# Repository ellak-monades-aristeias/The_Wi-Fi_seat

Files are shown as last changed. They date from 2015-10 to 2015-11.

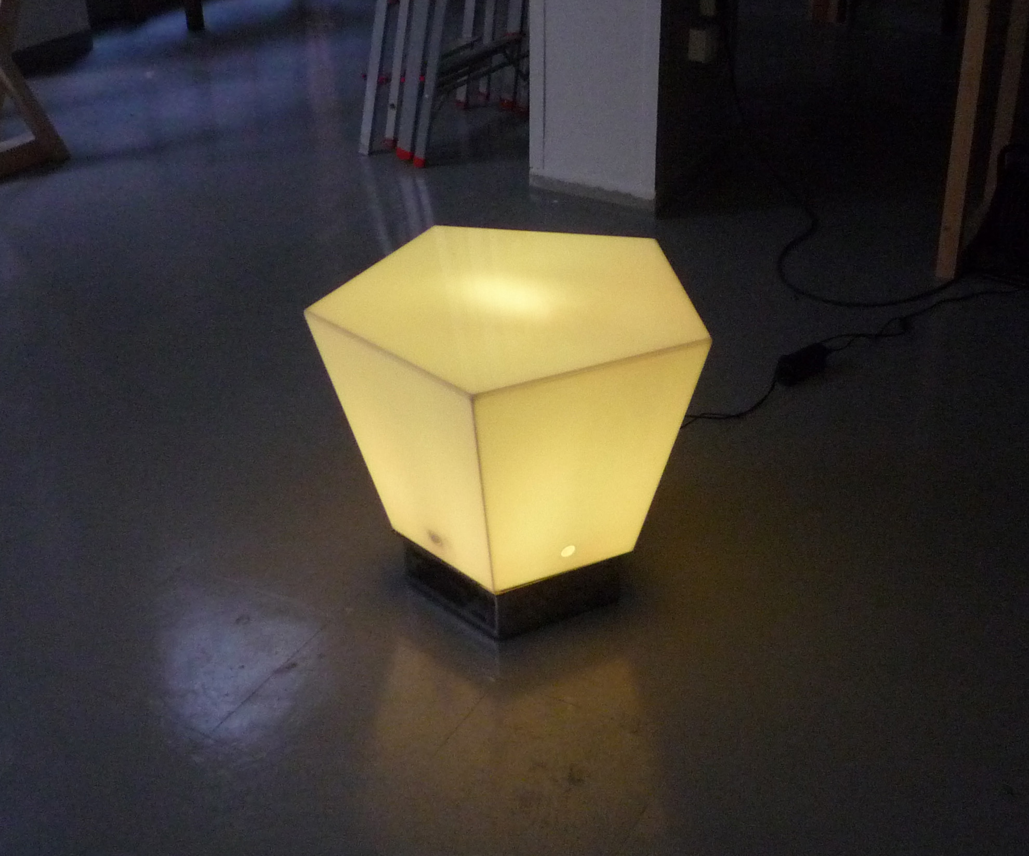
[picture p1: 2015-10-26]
images/signal_5.jpg

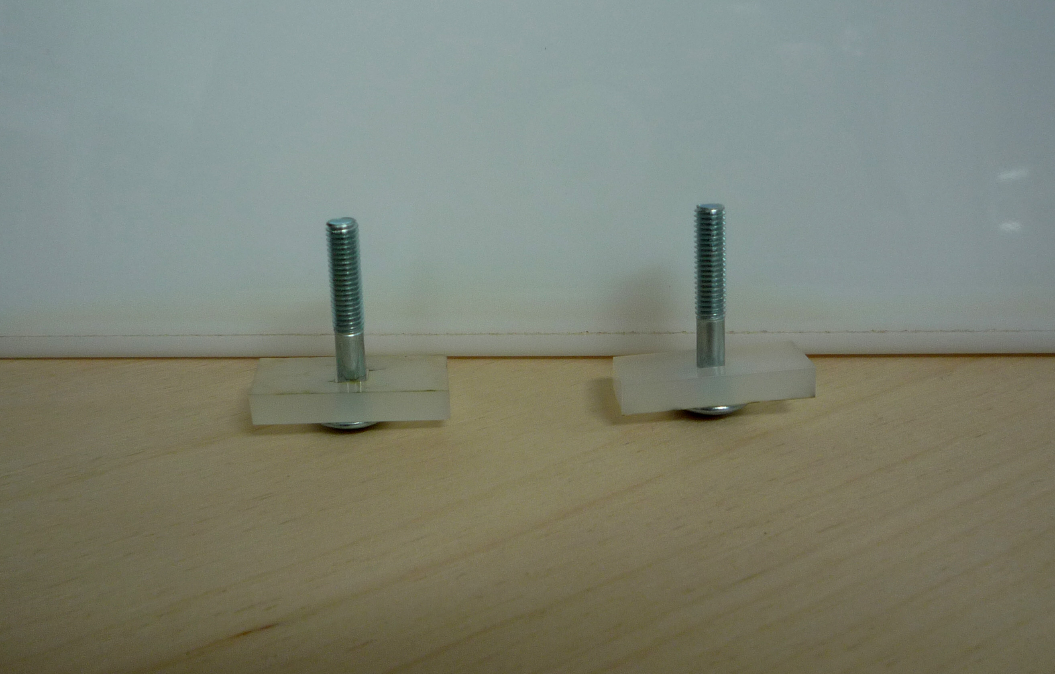
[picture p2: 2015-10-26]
images/screw_fixing_2.JPG

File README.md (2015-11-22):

# The_Wi-Fi_seat
## Περιγραφή της Πρότασης

Το Wi-Fi seat είναι κάθισμα εξωτερικού χώρου με ενσωματωμένο router που δίνει ελεύθερη πρόσβαση στο διαδίκτυο. Το κάθισμα κατασκευάζεται από plexiglass και είναι φωτιζόμενο. Ο φωτισμός διαφοροποιείται ως προς το χρώμα και ως προς την ένταση. Το χρώμα διαφοροποιείται από έντονο κόκκινο εως πράσινο αποτυπώνοντας την ένταση του σήματος Wi-Fi στην περιοχή. Η ένταση του φωτισμού του καθίσματος ρυθμίζεται ανάλογα με την κίνηση. Αν περνάει κάποιος κοντά στο κάθισμα, η ένταση θα δυναμώνει, αλλιώς θα είναι χαμηλή. Επιπλέον, η ένταση ρυθμίζεται ανάλογα με τον διάχυτο φωτισμό στην περιοχή.

Σκόπός της πρότασης είναι η δημιουργία ενός πόλου έλξης που θα ενθαρρύνει τη χρήση του δημόσιου χώρου από τους πολίτες, προσθέτοντας επιπλέον ασφάλεια μετά τη δύση του ηλίου (λόγω του φωτισμού), χωρίς να κοστίζει πολύ (λόγω της ρύθμισης της έντασης του φωτισμού).

Επιπλέον, με τη χρήση πολλών τέτοιων καθισμάτων σε διαφορετικά σημεία, δημιουργείται και ένα εικαστικό έργο που αποτυπώνει την ένταση του δικτύου WI-Fi της περιοχής. Έτσι οπτικοποιείται ένα πρόσθετο επίπεδο πληροφορίας που συνδέεται με το δομημένο περιβάλλον.

## Description

This is a perspex (plexiglass) seat for outdoor use that includes a wi-fi router, thus enabling up to 8 people to use the internet. The seat may work as a stand-alone wi-fi source, or as a mesh network (in a group of seats) that expands the municipality hotspots.

The seat is internally lit by led strips. The light colour is modified (from red to green) according to the strenght of the area wi-fi signal, the ambient lighting and nearby movement.

As a result, the seat encourages people to use public space and acts as a light source, adding an extra  sense of security  at a low cost. A group of Wi-Fi seats act as an artwork, visualizing the signal strenght as an extra information layer in the urban fabric.

## Κατασκευή

Το κάθισμα έχει μορφή κωνικού πενταγώνου, με τη μικρή διάμετρο στη βάση. Aποτελείται από τρία διακριτά στοιχεία: τη βάση, το περίβλημα και τον εσωτερικό πυρήνα.

Η βάση (σήματος πενταγώνου) κατασκευάζεται από μεταλλική γωνία 10x4cm, που βιδώνεται στο έδαφος με ειδικούς πείρους, και μεταλλική λάμα που εξέχει από την γωνία κατά 2cm, έτσι ώστε να υποδεχθεί το περίβλημα. Η λάμα έχει ειδικά ανοίγματα έτσι ώστε να υποδεχθεί τον εσωτερικό πυρήνα. Η βάση είναι γαλβανισμένη με ηλεκτροστατική βαφή.

Το περίβλημα κατασκευάζεται από φύλλα plexiglass, πάχους 10mm. Ο εσωτερικός πυρήνας έχει ορθογωνικό σχήμα και κατασκευάζεται από κόντρα πλακέ θαλάσσης 4mm. Οι πλευρές του είναι δυνατόν να κατασκευάστουν σε CNC καθώς «κουμπώνουν» η μία μέσα στην άλλη. Στην εξωτερική του πλευρά του στερεώνονται ταινίες led. Στο εσωτερικό του τοποθετείται ο διακομιστής (router), η κεραία, ο σένσορας έντασης του σήματος wi-fi καθώς και η πλακέτα που θα ρυθμίζει το χρώμα και την ένταση του φωτός, τύπου Arduino.

## Σύνδεση Wi-Fi

Το Wi-Fi seat διατίθεται σε δύο εκδόσεις από άποψη συνδεσιμότητας στο διαδίκτυο (Internet). Η μια διαθέτει δρομολογητή (router) με δυνατότητα διασύνδεσης τύπου 4G LTE ή 3G και παρέχει αυτόνομη πρόσβαση. Η δεύτερη διαθέτει δρομολογητή με δυνατότητα διασύνδεσης με άλλους δρομολογητές για την δημιουργία δικτύου πλέγματος (mesh network).

Η πρώτη έκδοση με αυτόνομο internet θα χρησιμοποιεί έναν δρομολογητή (router) τύπου D-Link 4G LTE. Προτιμήθηκε αυτός ο τύπος σε σχέση με κάποια έκδοση δρομολογητή με ανοιχτό λογισμικό (όπως τα OpenWrt, DD-WRT και HyperWRT) καθώς δεν υπάρχει διαθεσιμότητα ώριμης ανοιχτής λύσης ασύρματης δικτύωσης με διασύνδεση 4G LTE. Εναλλακτικά μπορεί να χρησιμοποιηθεί δρομολογητής TP-Link TL-MR3020 με λογισμικό OpenWrt και 3G modem Huawei E367 (με δυνατότητα HSPA+). Με αυτόν το δικτυακό εξοπλισμό, το Wi-Fi seat μπορεί να εξυπηρετήσει έως 5-8 χρήστες.

Η δεύτερη έκδοση εξοπλίζεται με δρομολογητή Open-Mesh OM5P-AN Dual Band και δίνει την δυνατότητα για την δημιουργία ενός δικτύου πλέγματος (mesh network) με την διασύνδεση διαφορετικών Wi-Fi seats. Μπορεί να εγκατασταθεί σε σημεία όπου υπάρχει ασύρματη πρόσβαση διαθέσιμη από τον Δήμο. Έτσι δίνεται η δυνατότητα να επεκταθεί η κάλυψη του δικτύου πέρα από τα όρια που θέτει η εγκατάσταση σημείων ασύρματης πρόσβασης του Δήμου (Wifi hotspots). Η δημιουργία δικτύων πλέγματος (mesh networks) μπορεί να χρησιμοποιηθεί και χωρίς την πρόσβαση στο διαδίκτυο για τη δημιουργία μιας κοινότητας χρηστών που αξιοποιούν το δίκτυο για εφαρμογές όπως τα παιχνίδια (gaming), οι συνομιλίες (chat)και οι κλήσεις (VoIP).

Για τους σκοπούς της επίδειξης θα χρησιμοποιηθεί δρομολογητής DLink mi-fi (mobile wi-fi) που τροφοδοτείται από μπαταρία. Έτσι θα υπάρχει αυτονομία της κατασκευής ως αναφορά την πρόσβαση στο διαδίκτυο.

## Έλεγχος έντασης και χρώματος φωτισμού

Πάνω στον εσωτερικό πυρήνα τοποθετούνται ταινίες LED. Περιμετρικά τοποθετούνται σένσορες κίνησης τύπου PIR (Passive Infrared" ή "Pyroelectric), οι οποίοι έχουν ακτίνα 180 μοίρες.

Ο έλεγχος της έντασης του σήματος και συνεπώς της φωτεινότητας επιτυγχάνεται με τη χρήση μικρής πλακέτας τύπου Arduino, η οποία τοποθετείται μέσα στον ξύλινο πυρήνα του καθίσματος και προγραμματίζεται με ελεύθερο λογισμικό. Οι σένσορες κίνησης στέλνουν σήμα στην πλακέτα, ή οποία με χρήση MOSFET τρανζίστορ επηρεάζει το ηλεκτρικό σήμα προς τις LED ταινίες.

Κατά τις περιόδους που οι σένσορες δεν εντοπίζουν κίνηση, οι φωτεινότητα θα μειώνεται και θα παραμένει σε χαμηλά επίπεδα για εξοικονόμηση ενέργειας. Μία συγγενής εφαρμογή βρίσκεται σήμερα ήδη σε πιλοτική φάση σε προάστιο της Κοπεγχάγης, όπου η ένταση του φωτισμού από στήλους στο δρόμο μειώνεται αισθητά όταν κίνηση οχημάτων δεν εντοπίζεται στο δρομό. Επιπλέον, στο arduino σύστημα τοποθετείται ειδικό; σένσορα φωτεινότητας προκειμένου να ρυθμίζεται η ένταση του φωτισμού όταν ο γενικός φωτισμός είναι σε υψηλά επίπεδα.

Ο φωτισμός διαφοροποιείται ως προς το χρώμα και ως προς την ένταση. Το χρώμα των Led διαφοροποιείται από έντονο κόκκινο εως πράσινο αποτυπώνοντας την ένταση του σήματος Wi-Fi στην περιοχή. Η λειτουργία αυτή ρυθμίζεται επίσης μέσω ειδικού σένσορα που συνδέεται στην πλακέτα Arduino.

Το κάθισμα θα συνδέεται με ηλεκτρικό ρεύμα από την κοντινότερη πηγή, σε συνεννόηση με τον Δήμο.

## Συντήρηση

Για τη συντήρηση, αφαιρείται το περίβλημα του καθίσματος με κρυφές βίδες.

## Σε ποιους απευθύνεται - Κοινότητες Χρηστών - Developers ##
Η χρήση του τελικού προϊόντος του έργου είναι για ερευνητικούς σκοπούς στο πλαίσιο της "έξυπνης πόλης".

## Κόστος ##
Το κόστος για 1 τεμάχιο είναι 908 Ευρώ, για 10 τεμάχια 688 Ευρώ (το ένα) και για 100 τεμάχια 650 Ευρώ (το ένα).

## Οδηγίες Χρήσης

Η κατασκευή και χρήση περιγράφεται στην ενότητα wiki. Οδηγίες για προγραμματιστές δίνονται στην ενότητα arduino code, με γενική περιγραφή και σχόλια μέσα στον κώδικα.

## Πίνακας Παραδοτέων
ARDUINO CODE <br>
ESP-wifi-power_ignoreAP.ino <br>
readme <br>
wifi_seat_easy.ino <br>

COST ANALYSIS <br>
Cost Analysis <br>

DWG <br>
A-01_plan_elevation_section <br> 
A-02_base <br> 
A-03_box <br> 
A-04_plexiglass <br>
base_complete <br>
base_sheet <br>
base_top_view <br>
box.jpg <br>
plexiglass.jpg <br>

DXF <br>
A-01_plan_elevation_section <br>
A-02_base <br>
A-03_box <br>
A-04_plexiglass <br>
base_complete <br>
base_sheet <br>
base_top_view <br>
box.jpg <br>
plexiglass.jpg <br>

IMAGES <br>
board <br>
open_box <br>
box_reinforcement <br> 
screw_fixing_1 <br>
screw_fixing_2 <br>
signal_1 <br>
signal_2 <br>
signal_3 <br>
signal_4 <br>
signal_5 <br>
wi-fi_seat-A3_colours <br>
wi-fi_seat_day <br>
wi-fi_seat_night <br>

PDF <br>
A-01_plan_elevation_section <br>
A-02_base <br>
A-03_box <br>
A-04_plexiglass <br>

ΓΕΝΙΚΑ ΑΡΧΕΙΑ <br>
README.md <br> 
licence <br>
wi-fi_seat-construction_stages <br>
wi-fi_seat-intro <br>
ταυτότητα έργου <br>

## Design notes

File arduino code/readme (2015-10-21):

This code runs on an Arduino UNO board, connected with an ESP 8266. See the source code for precise instructions on setting everything up.

It scans nearby WiFi networks, and uses the detected signal level, together with data about local illumination and movements, to control the illumination from the seat.

Code by Andrea Fasolo Rao for 2MONOCHANNELS
raoandrea@gmail.com - giorgos@2monochannels.com

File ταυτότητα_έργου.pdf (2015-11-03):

### The Wi-Fi seat

https://github.com/ellak-monades-aristeias/The_Wi-Fi_seat.git Ομάδα μελέτης:
Όλγα Βενετσιάνου, Δρ. Αρχιτέκτων
Ηρακλής Λαμπρόπουλος, Integrated Design Consultant Κυριάκος Σάτλας, Δρ. Ηλεκτρολόγος Μηχανικός

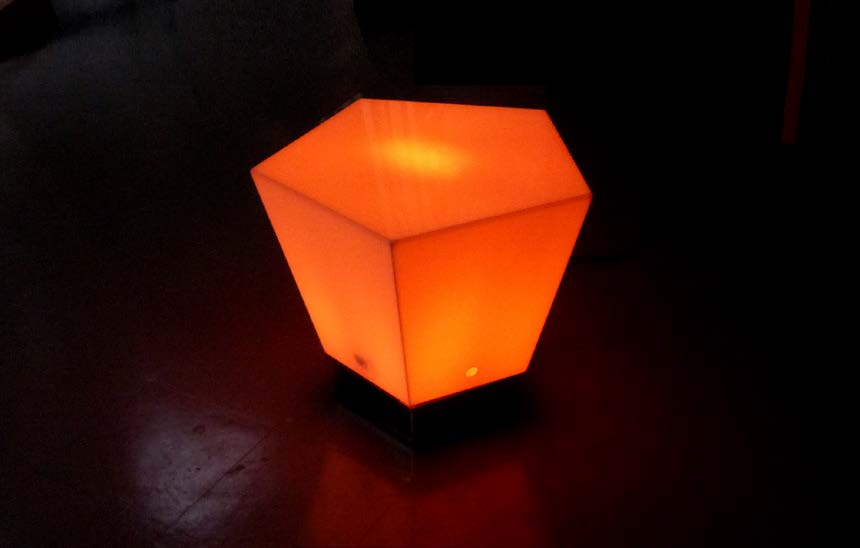
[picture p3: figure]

Φωτογραφία του πρωτοτύπου

Περιγραφή του έργου

Το Wi-Fi seat είναι κάθισμα εξωτερικού χώρου με ενσωματωμένο δρομολογητή (router) που δίνει ελεύθερη πρόσβαση στο διαδίκτυο. Προτείνονται δύο τύποι σύνδεσης: στην πρώτη περίπτωση ο δρομολογητής λειτουργεί αυτόνομα, ενώ στη δεύτερη χρησιμοποιούνται πολλά καθίσματα και επεκτείνονται τα hot-spots του Δήμου.
Το κάθισμα κατασκευάζεται από plexiglass και είναι φωτιζόμενο. Ο φωτισμός διαφοροποιείται ως προς το χρώμα και ως προς την ένταση. Το χρώμα διαφοροποιείται από έντονο κόκκινο εως πράσινο αποτυπώνοντας την ένταση του σήματος Wi-Fi στην περιοχή. Η ένταση του φωτισμού του καθίσματος ρυθμίζεται ανάλογα με την κίνηση. Αν περνάει κάποιος κοντά στο κάθισμα, η ένταση θα δυναμώνει, αλλιώς θα είναι χαμηλή. Επιπλέον, η ένταση ρυθμίζεται ανάλογα με τον διάχυτο φωτισμό στην περιοχή.

Χρήση του έργου
Το έργο έχει λειτουργική αλλά και εικαστική χρήση. Σκόπός της πρότασης είναι η δημιουργία ενός πόλου έλξης που θα ενθαρρύνει τη χρήση του δημόσιου χώρου από τους πολίτες με την παροχή σύνδεσης με το διαδίκτυο, προσθέτοντας επιπλέον ασφάλεια μετά τη δύση του ηλίου (λόγω του φωτισμού), χωρίς να κοστίζει πολύ (λόγω της ρύθμισης της έντασης του φωτισμού).
Επιπλέον, με τη χρήση πολλών τέτοιων καθισμάτων σε διαφορετικά σημεία, δημιουργείται και ένα εικαστικό έργο που αποτυπώνει την ένταση του δικτύου WI-Fi της περιοχής. Έτσι οπτικοποιείται ένα πρόσθετο επίπεδο πληροφορίας που συνδέεται με το δομημένο περιβάλλον.

Προαπαιτούμενα για τη χρήση του έργου
Απαιτείται σύνδεση με ρεύμα (στο κέντρο του καθίσματος). Υπάρχουν δύο επιλογές για τον δρομολογητή (router): Είτε λειτουργεί μς κάτρα SIM, είτε συνδέεται σε hot spot του Δήμου.

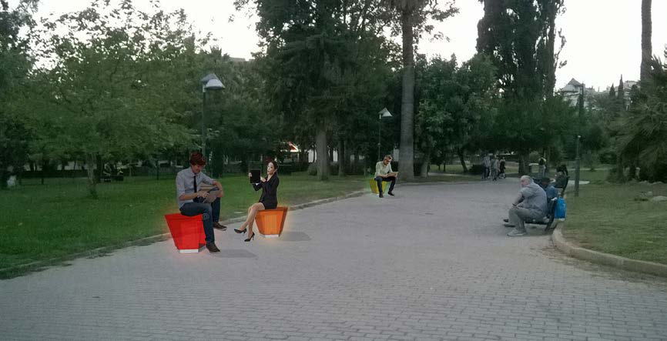
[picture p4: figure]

Φωτορεαλιστική απεικόνιση (μέρα)

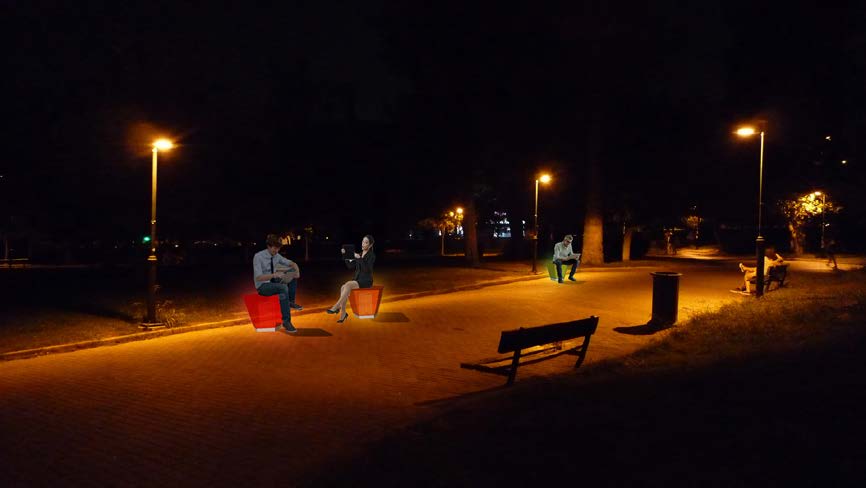
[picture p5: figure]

Φωτορεαλιστική απεικόνιση (βράδυ)

Είδος | Μονάδα Μέτρησης | Ποσότητα | Τιμή (Euro) | Σύνολο ver 1 (Euro) (1 τεμάχιο) | Σύνολο ver 2 (Euro) (1 τεμάχιο) | Σύνολο ver 3 (Euro) (1 τεμάχιο) | Σύνολο ver 1 (Euro) (10 τεμάχια) | Σύνολο ver 2 (Euro) (10 τεμάχια) | Σύνολο ver 3 (Euro) (10 τεμάχια) | Σύνολο (Euro) ver 1 (100 τεμάχια) | Σύνολο ver 2 (Euro) (100 τεμάχια) | Σύνολο ver 3 (Euro) (100 τεμάχια)
Περίβλημα plexiglass γαλακτερό 10mm Μεταλλική βάση (γαλβανισμένη με | Τεμάχιο Τεμάχιο | 1 1 | 250 315 | 250 315 | 250 | 250 | 230 | 230 | 230 | 200 | 200 | 200
ηλεκτροστατική βαφή) Πυρήνας από κόντρα πλακέ | τεμάχιο | 1 | 25 | 25 | 315 | 315 | 115 | 115 | 115 | 107 | 107 | 107
θαλάσσης LED Strips 30cm | Τεμάχιο | 4 | 12 | 48 | 25 48 | 25 48 | 25 48 | 25 48 | 25 48 | 25 48 | 25 48 | 25 48
LED Strips 20cm | Τεμάχιο | 1 | 10 | 10 | 10 | 10 | 10 | 10 | 10 | 10 | 10 | 10
Σενσορας PIR, daylight, και | Τεμάχιο | 6 | 5 | 30
Πλακέτα Arduino ΟΝΕ | Τεμάχιο | 1 | 30 | 30 | 30 | 30 | 30 | 30 | 30 | 30 | 30 | 30
σένσορας wifi Power supply | Τεμάχιο | 1 | 20 | 20 | 30 20 | 30 20 | 30 20 | 30 20 | 30 20 | 30 20 | 30 20 | 30 20
Δρομολογητής 4G LTE | Τεμάχιο | 1 | 240 | 240 | | | 240 | | | 240
Δρομολογητής 3G | | 1 | | | 180 | | | 180 | | | 180
Δρομολογητής Open Mesh | | 1 | | | | 180 | | | 180 | | | 180
Ή | | Ή | | | Ή | | | Ή
Ή | | | Ή | | | Ή | | | Ή
ΣΥΝΟΛΟ | 968 | 908 | 908 | 748 | 688 | 688 | 710 | 650 | 650

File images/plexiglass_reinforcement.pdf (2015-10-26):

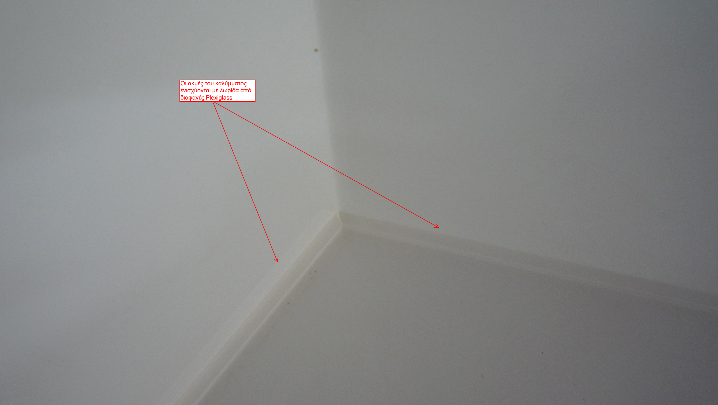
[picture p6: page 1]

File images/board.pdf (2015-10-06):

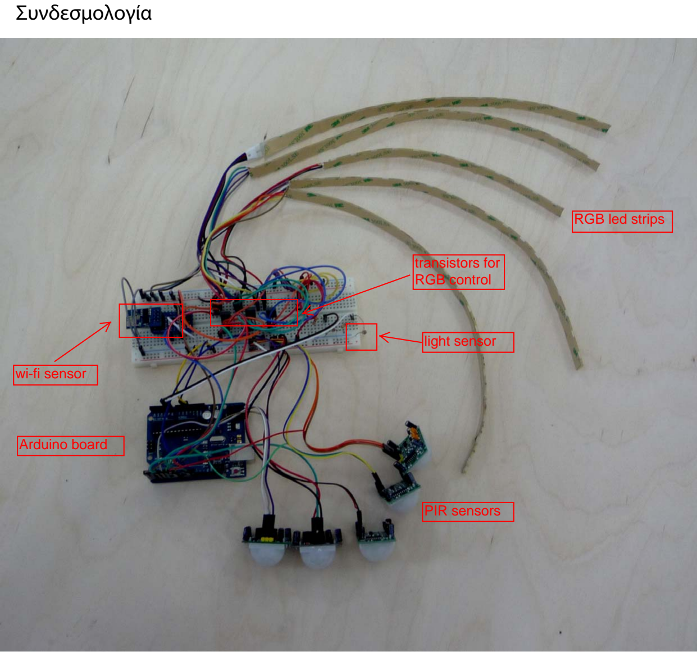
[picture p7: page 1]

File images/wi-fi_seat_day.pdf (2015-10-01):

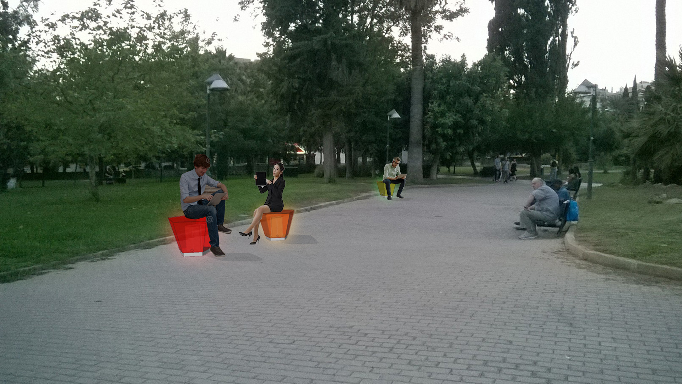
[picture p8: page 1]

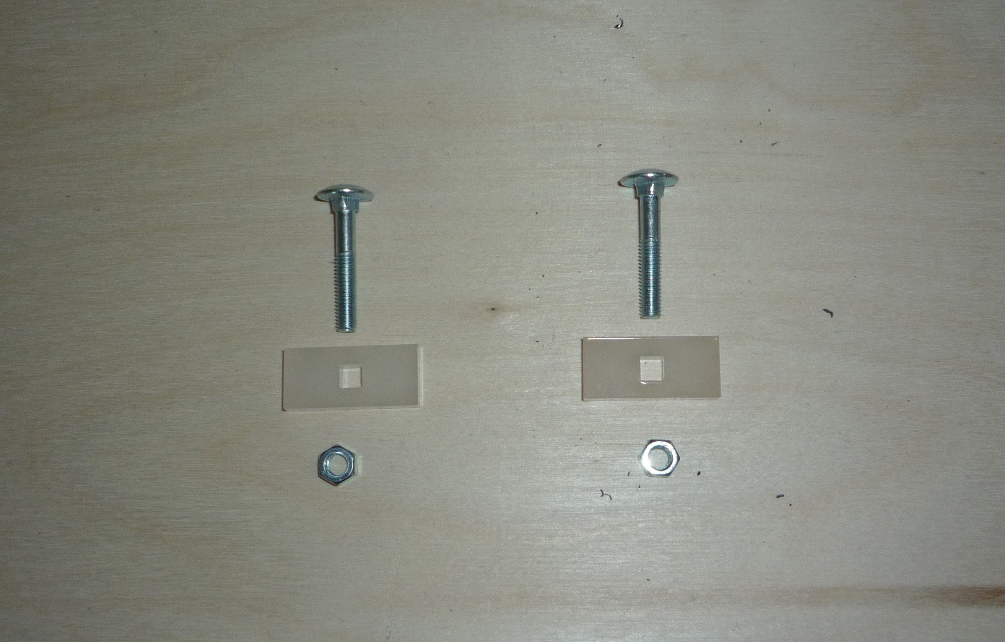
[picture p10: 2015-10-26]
images/screw_fixing_1.JPG

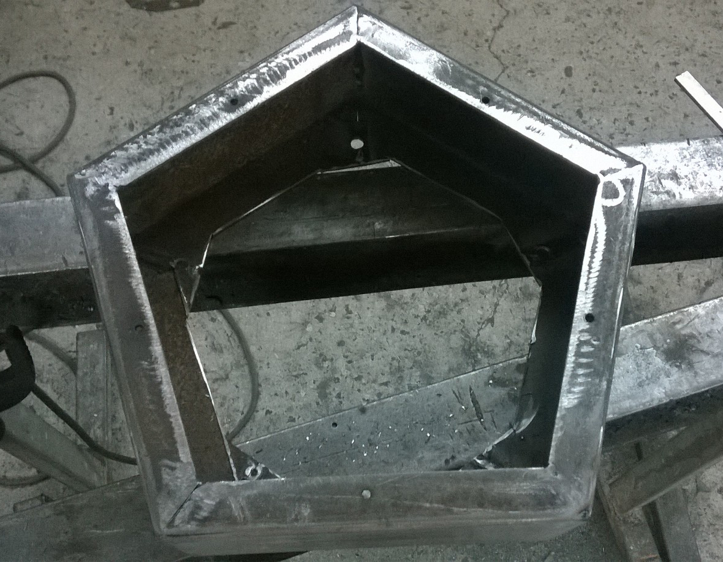
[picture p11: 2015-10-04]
dxf/base_top_view.jpg

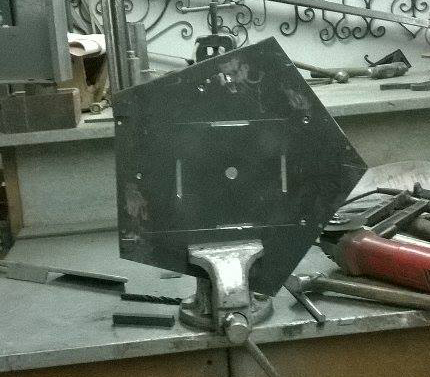
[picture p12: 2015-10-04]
dxf/base_sheet.jpg

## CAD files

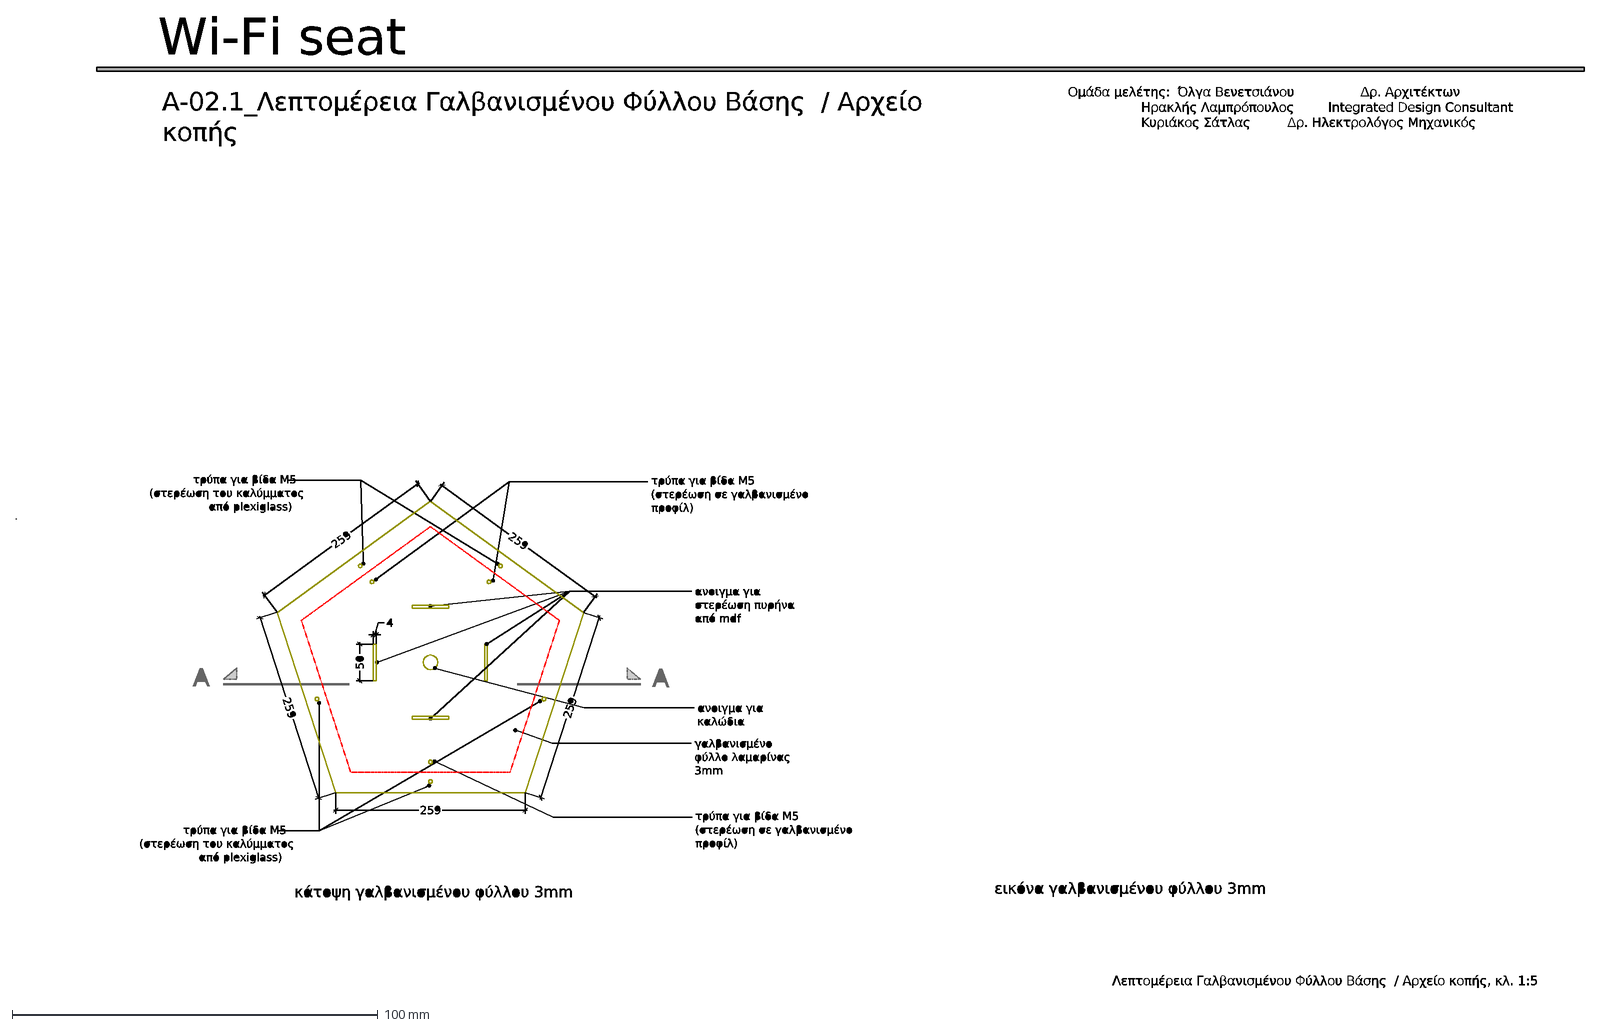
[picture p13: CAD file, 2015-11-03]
dxf/A-02_base.dxf
Wi-Fi seat
Ομάδα μελέτης: Όλγα Βενετσιάνου Δρ. Αρχιτέκτων Ηρακλής Λαμπρόπουλος Integrated Design Consultant Κυριάκος Σάτλας Δρ. Ηλεκτρολόγος Μηχανικός
Λεπτομέρεια Γαλβανισμένου Φύλλου Βάσης / Αρχείο κοπής, κλ. 1:5
A-02.1_Λεπτομέρεια Γαλβανισμένου Φύλλου Βάσης / Αρχείο κοπής

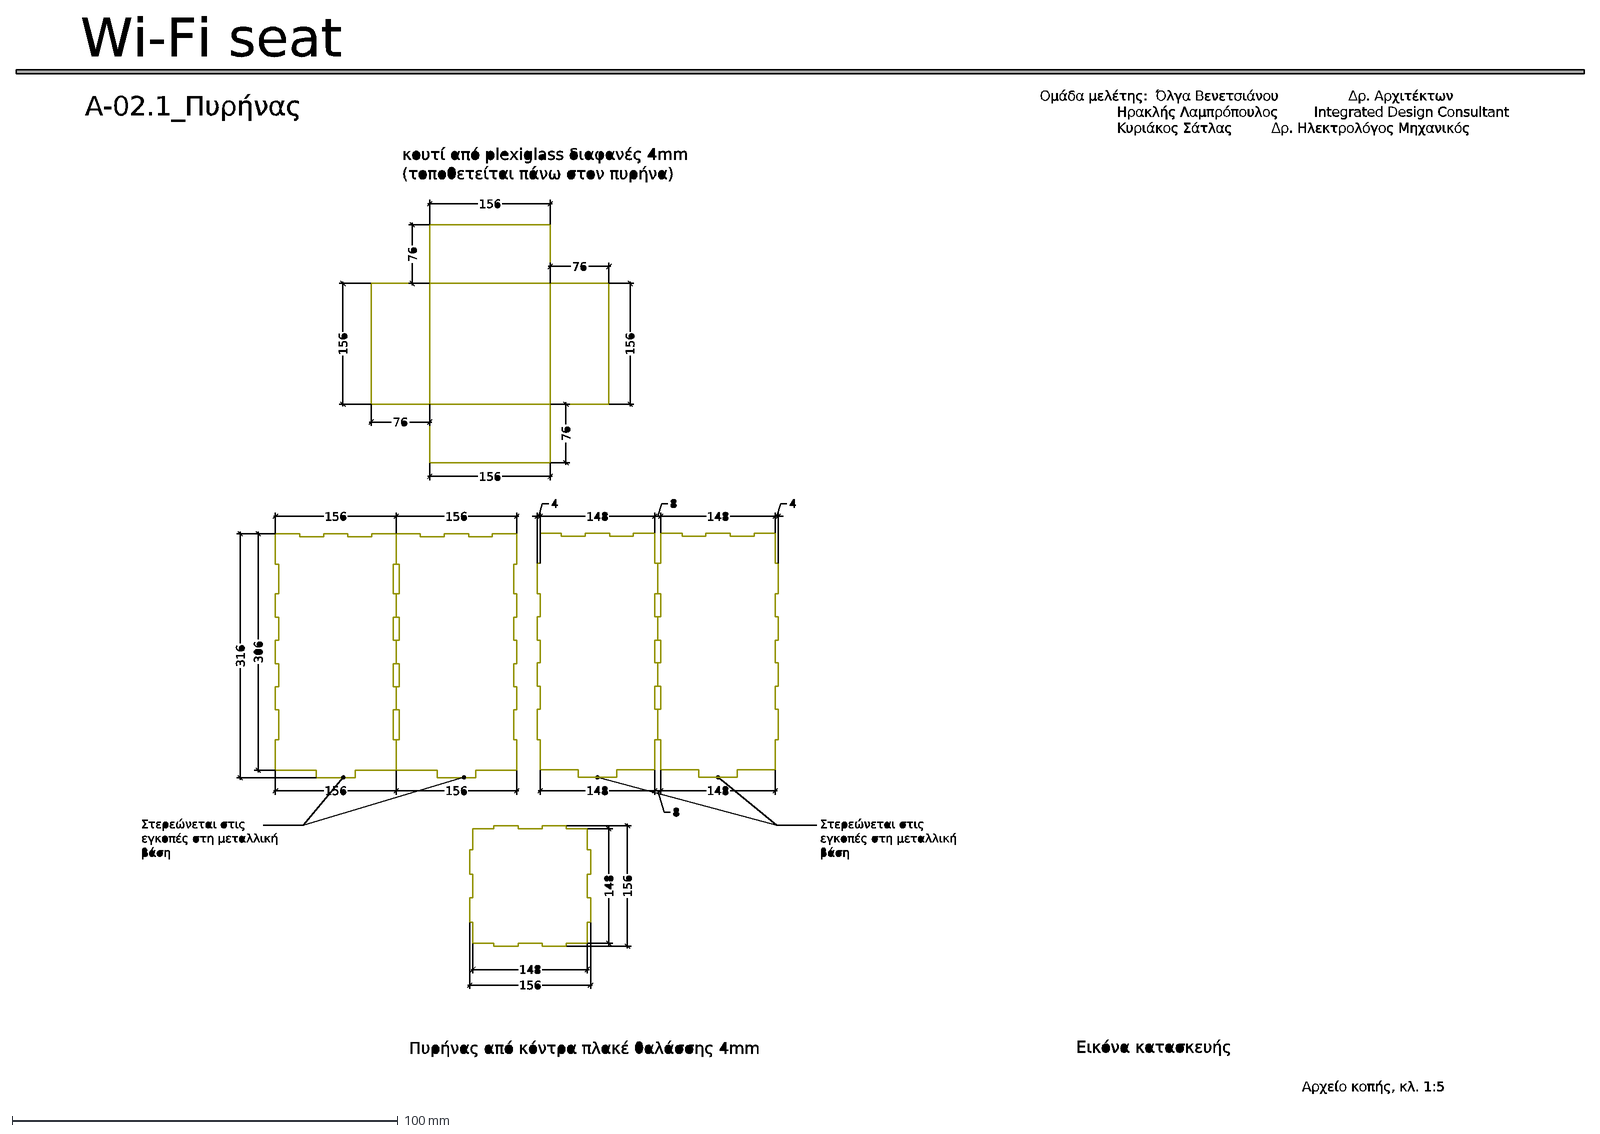
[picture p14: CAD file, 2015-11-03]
dxf/A-03_box.dxf
Wi-Fi seat
Ομάδα μελέτης: Όλγα Βενετσιάνου Δρ. Αρχιτέκτων Ηρακλής Λαμπρόπουλος Integrated Design Consultant Κυριάκος Σάτλας Δρ. Ηλεκτρολόγος Μηχανικός
Αρχείο κοπής, κλ. 1:5
A-02.1_Πυρήνας

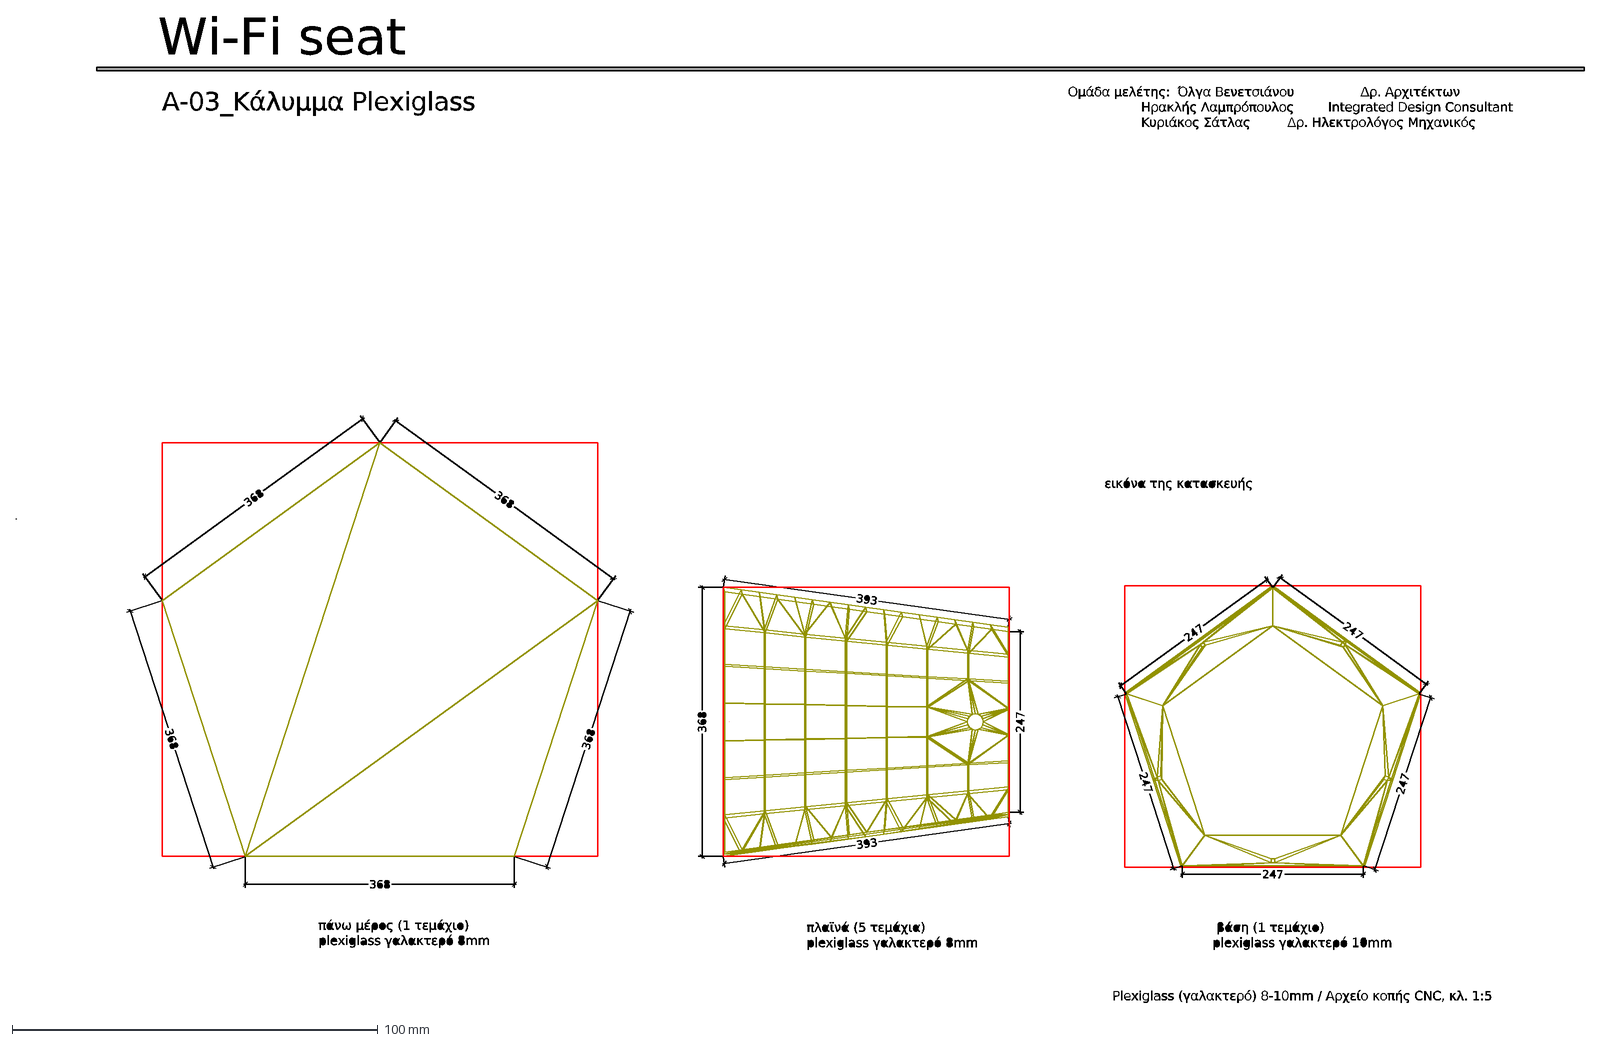
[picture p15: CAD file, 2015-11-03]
dxf/A-04_plexiglass.dxf
Wi-Fi seat
Ομάδα μελέτης: Όλγα Βενετσιάνου Δρ. Αρχιτέκτων Ηρακλής Λαμπρόπουλος Integrated Design Consultant Κυριάκος Σάτλας Δρ. Ηλεκτρολόγος Μηχανικός
Plexiglass (γαλακτερό) 8-10mm / Αρχείο κοπής CNC, κλ. 1:5
A-03_Κάλυμμα Plexiglass

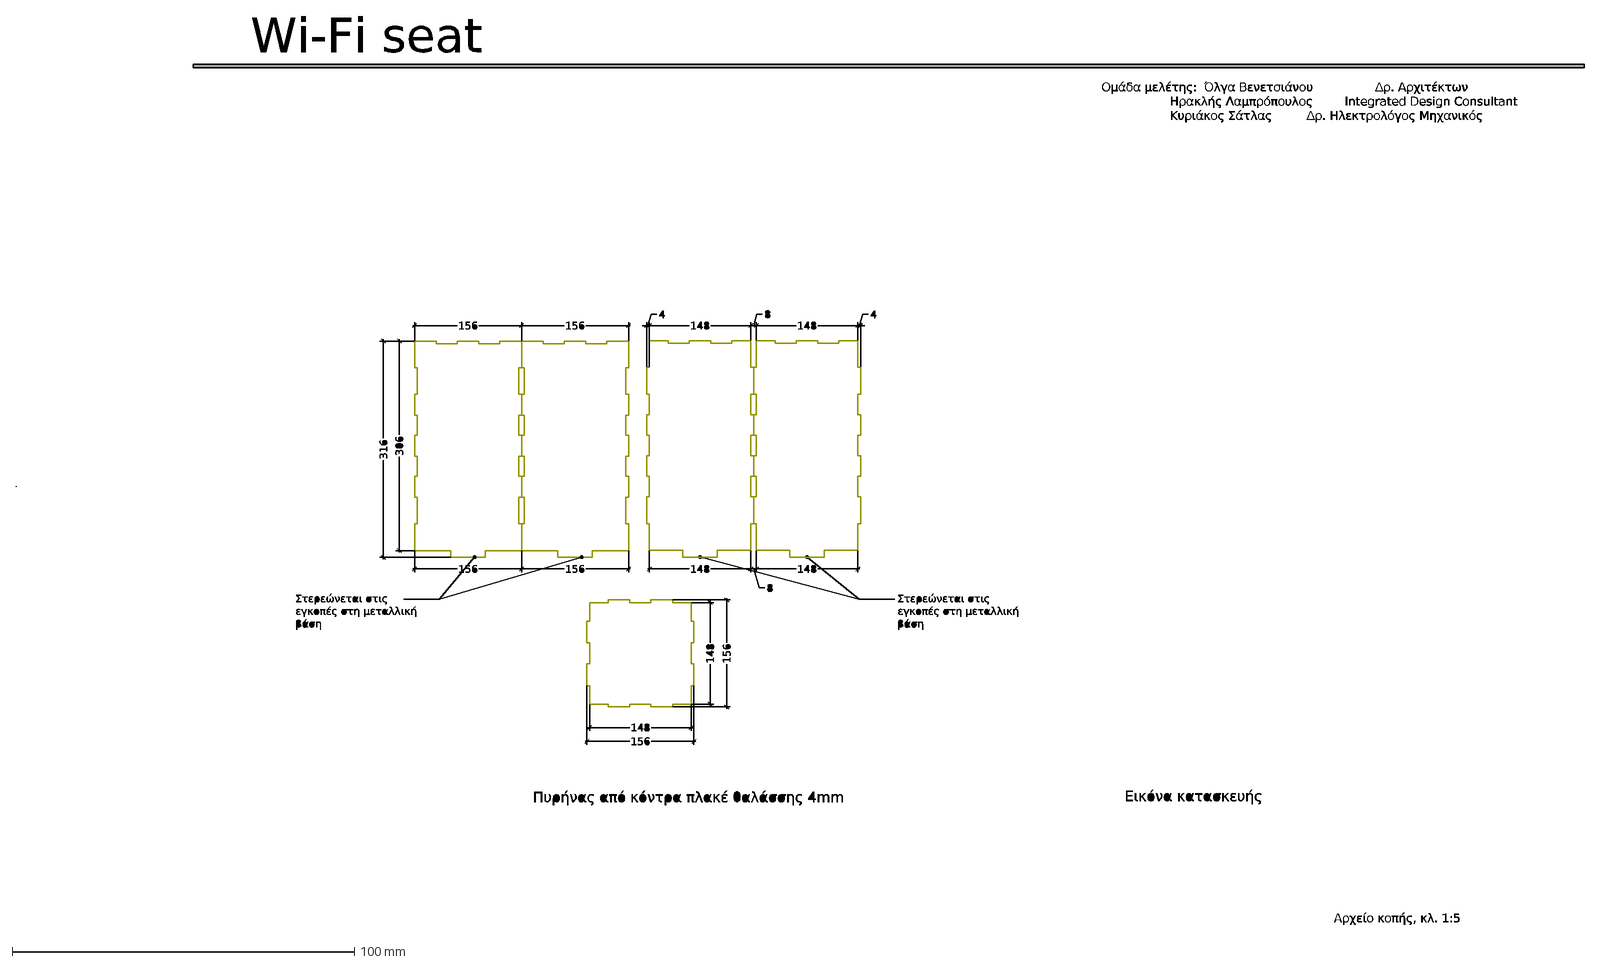
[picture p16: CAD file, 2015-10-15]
dxf/box.dxf
Wi-Fi seat
Ομάδα μελέτης: Όλγα Βενετσιάνου Δρ. Αρχιτέκτων Ηρακλής Λαμπρόπουλος Integrated Design Consultant Κυριάκος Σάτλας Δρ. Ηλεκτρολόγος Μηχανικός
Αρχείο κοπής, κλ. 1:5

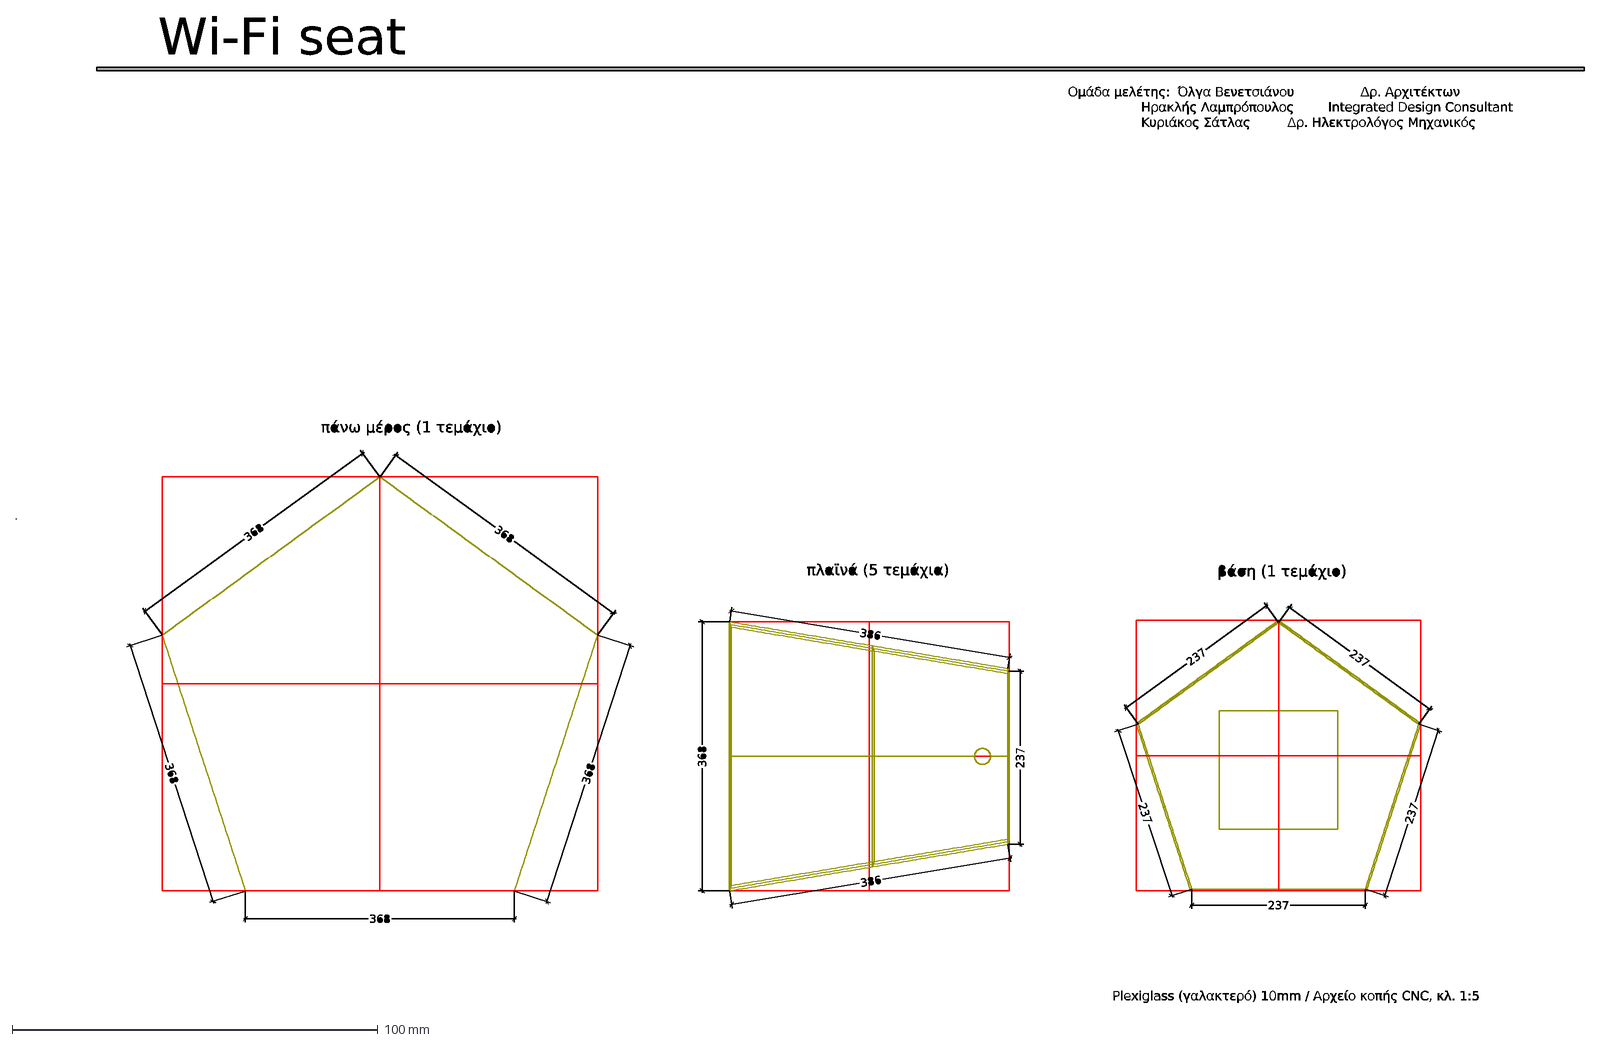
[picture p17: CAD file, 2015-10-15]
dxf/plexiglass.dxf
Wi-Fi seat
Ομάδα μελέτης: Όλγα Βενετσιάνου Δρ. Αρχιτέκτων Ηρακλής Λαμπρόπουλος Integrated Design Consultant Κυριάκος Σάτλας Δρ. Ηλεκτρολόγος Μηχανικός
Plexiglass (γαλακτερό) 10mm / Αρχείο κοπής CNC, κλ. 1:5

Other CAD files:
dxf/A-01_plan_elevation_section.dxf
dxf/plan_elevation_section.dxf
dwg/A-01_plan_elevation_section.dwg
dwg/A-02_base.dwg
dwg/A-03_box.dwg
dwg/A-04_plexiglass.dwg

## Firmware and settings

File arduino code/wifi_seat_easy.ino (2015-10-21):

/*
 * 
 * This code is meant to be uploaded to an Arduino UNO board
 * 
 * This code sends a "getdata" request to an ESP8266 module connected via serial and expects to get back a positive integer number,
 * representing the power in dBm of the best WiFi network around.
 * 
 * Also, two photoresistors collects informations about the light level around the seat.
 *  
 * Then, it uses these values to control the color and the brightness of RGB LEDs.
 * 
 * The LEDs gets brighter when someone approaches, sensed by 5 PIR sensors.
 * 
 * Created in October 2015 - Andrea Fasolo Rao for 2MONOCHANNELS
 * raoandrea@gmail.com - giorgos@2monochannels.com
 * 
 */


/*
 *  Pins used to connect sensors and LEDs - ESP8266 must be connected to 0 and 1
 */

int ledPin = 13;  //using integrated LED for debug

int pirPins[] = {3,4,5,6,7};  //PIR (passive infrared sensors) pins

int redPin = 9;     //RGB LEDs pins
int greenPin = 10;
int bluePin = 11;

float redVal = 255; //values to control LEDs
float grnVal = 255;
float bluVal = 255;

int lightPin1 = A0; //photoresistors pins
int lightPin2 = A1;

float lightValue;   //mean value from the light sensors
int maxValue = 75;

int calibrationTimeSec = 20;  //time required to calibrate PIRs

long unsigned int lowIn;      //the time when the sensor outputs a low impulse

//the amount of milliseconds the sensor has to be low 
//before we assume all motion has stopped
long unsigned int pause = 500;  

boolean lockLow = true;   //helping variable for PIRs 
boolean takeLowTime;      //time required to read "low" from the PIRs

boolean PirStatus = false;  //current global status of the PIRs
boolean PirStatuses[] = {false, false, false, false, false}; //array with the statuses for every single PIR
int PirCount = 0;           //number of PIRs reporting movement


float maxBrightness = 100;  //max brightness of the LEDs
float minBrightness = 15;   //min brightness of the LEDs
float brightness = 50;      //brightness of the LEDs

boolean stringComplete = false;     //checks if the string from the serial port is complete
String inputString="";              //string incoming from the serial port
unsigned long lastUpdate = millis();  
unsigned long waitTime = 10000;     //time between requests to the WiFi module
String data = "";                   //data from the serial port

float ledcolor = 0;                 //"one variable to rule them all" - from this number will be calculated R G and B values
float input = 100;


int pirCounter = 3;


unsigned long lightWaitTime = 250;    //time betweend photoresistors readings
unsigned long lightLastUpdate = millis();

unsigned long PirWaitTime = 500;      //time between PIRs readings
unsigned long PirLastUpdate = millis();

unsigned long wifiWaitTime = 20000;   //time between wifi power requests
unsigned long wifiLastUpdate = millis();


void setup() {              //this code runs once
  
  Serial.begin(115200);     //start serial communication. Speed depends on the revision of the module
  
  pinMode(ledPin, OUTPUT);  //setting the used pins to INPUT or OUTPUT
  digitalWrite(ledPin, LOW);
  
  pinMode(redPin, OUTPUT);
  pinMode(greenPin, OUTPUT);
  pinMode(bluePin, OUTPUT);
  
  pinMode(lightPin1, INPUT);
  pinMode(lightPin2, INPUT);


  pinMode(pirPins[0], INPUT);
  pinMode(pirPins[1], INPUT);
  pinMode(pirPins[2], INPUT);
  pinMode(pirPins[3], INPUT);
  pinMode(pirPins[4], INPUT);
  
  
  lightValue = maxValue;

  analogWrite(redPin, 255);   //routine to check that the LEDs are working fine
  analogWrite(greenPin, 255);
  analogWrite(bluePin, 255);

  delay(1000);

  analogWrite(redPin, 0);
  analogWrite(greenPin, 0);
  analogWrite(bluePin, 0);

  delay(1000);

  analogWrite(redPin, 255);
  analogWrite(greenPin, 255);
  analogWrite(bluePin, 255);

  delay(1000);

  analogWrite(redPin, 255);
  analogWrite(greenPin, 0);
  analogWrite(bluePin, 0);

  delay(1000);

  analogWrite(redPin, 0);
  analogWrite(greenPin, 255);
  analogWrite(bluePin, 0);

  delay(1000);

  analogWrite(redPin, 0);
  analogWrite(greenPin, 0);
  analogWrite(bluePin, 255);

  delay(1000);

  analogWrite(redPin, 50);
  analogWrite(greenPin, 0);
  analogWrite(bluePin, 50);
  
  // PIR SENSOR CALIBRATION
  delay(calibrationTimeSec*1000);

  float lightValue1 = analogRead(lightPin1);    //reads photoresistors values
  float lightValue2 = analogRead(lightPin2);
  lightValue = (lightValue1 + lightValue2) / 2;
  lightValue = lightValue/4;                    //read values are 0-1024, output msut be 0-255, so we adapt that

  PirStatus = false;                            //Setting the PIRs readings to false before making a new read
  PirCount = 0;
    for (int i = 3; i < 8; i++){                //reading all the PIRs
      PirStatuses[i] = digitalRead(pirPins[i]);
      if (PirStatuses[i]){                      //everytime a PIR reports movement...
        PirCount++;                             //increase the count
      }
    }

    if (PirCount >= 3){                         //if at least three PIRs are positive, report movement globally
      PirStatus = true;
    }
    else {
      PirStatus = false;
    }

  Serial.println("getdata");  //first request for data
  delay(2000);

  wifiLastUpdate = millis() - 19000;            //first wifi request will be in one second instead of twenty

}

void loop() {       //this code keeps repeating

  while ((millis() - lightLastUpdate) > lightWaitTime){ //if lightWaitTime is passed, read new light values
    
    float lightValue1 = analogRead(lightPin1);
    float lightValue2 = analogRead(lightPin2);
    lightValue = (lightValue1 + lightValue2) / 2;
    lightValue = int(lightValue/4);                     //scaling from 0-1024 to 0-255
    
    lightLastUpdate = millis();
  }

  while ((millis() - PirLastUpdate) > PirWaitTime){     //if PirWaitTime is passed, read new PIRs values
    
    PirStatus = false;
    PirCount = 0;
    
    for (int i = 3; i < 8; i++){      //reading all the PIRs
      PirStatuses[i] =  digitalRead(pirPins[i]);
      if (PirStatuses[i]){            //everytime a PIR reports movement...
        PirCount++;                   //increase the count
      }
    }

    if (PirCount >= 3){               //if at least three PIRs are positive, report movement globally
      PirStatus = true;
    }
    else {
      PirStatus = false;
    }

      PirLastUpdate = millis();
  }

    maxBrightness = lightValue;     //the maximum brightness of the LEDs depends on the light received by the light sensor

  if (!PirStatus){                  //creates a smooth transition when dimming or brightening the LEDs
    if (brightness > minBrightness){
      brightness--;
      delay(2);
    }
  }
  if (PirStatus){
    if (brightness < maxBrightness){
      brightness++;
      delay(2);
    }
  }

  float aredVal = (redVal/255) * brightness;  //the R G B values are scaled with the current brightness value
  float agrnVal = (grnVal/255) * brightness;
  float abluVal = (bluVal/255) * brightness;


  analogWrite(redPin, aredVal);             //writes values to the LEDs
  analogWrite(greenPin, agrnVal);
  analogWrite(bluePin, abluVal);

  // READING SENSORS!

  while (millis() - wifiLastUpdate > wifiWaitTime){ //if wifiWaitTime is passed, sends a new request for the wifi power

    digitalWrite(ledPin,HIGH);  // debug pin dance for feedback
    delay(100);
    digitalWrite(ledPin,LOW);
    delay(50);
    digitalWrite(ledPin,HIGH);
    delay(100);
    digitalWrite(ledPin,LOW);
    delay(50);
    digitalWrite(ledPin,HIGH);
    delay(100);
    digitalWrite(ledPin,LOW);
    
    Serial.println("getdata");  // requesting data to ESP
    unsigned long now = millis();

    while (!stringComplete) {   //waits 5 seconds for a valid response from the ESP
          serialEvent();        //checks serial port for incoming data
          if (millis() > now + 5000) {
            blinknok();         //debug pin dance to report a problem 
            break;
          }
    }

    if (stringComplete==true)  {                                        //when the string from the serial port is complete..
            String bb=inputString.substring(0, inputString.length()-1); //...takes the input string, cutting off the last character
            Serial.println(bb);
            data=bb;
            blinkok();            //debug pin dance for feedback
            lastUpdate=millis();
        }

        inputString = "";         //the String with the incoming characters is cleared
        stringComplete = false;   //and the conditions set to false

        String aa="";

        for (int i=0; i<data.length(); i++)  {              //checks the incoming string for a ";" character, wich marks the end of the string
          aa+=data.substring(i,i+1);
          if (data.substring(i,i+1)==";") {
              input=aa.substring(0,aa.length()-1).toInt();  //takes only the dBm value without the ";" and converts it to integer
              aa="";                                        //string cleared
          }
        }

        if (input != 0){          //if the value received is not zero...

          ledcolor = input * 2,55;  // converts it from dBm to a number and then a color

          redVal = ledcolor;
          grnVal = 255 - ledcolor;
          bluVal = 0;
        }
        
    wifiLastUpdate = millis();
  }
  

}


void serialEvent() {
      while (Serial.available()) {            //when the serial port is free...
          
          char inChar = (char)Serial.read();  //get the new byte
          inputString += inChar;              //add it to the inputString:
          if (inChar == '\n') {               // if the incoming character is a newline, set the string as complete
                stringComplete = true;
          }
      }
}

void blinkok(){       // debug function "Blink OK"
  delay(1000);
  digitalWrite(13,HIGH);
  delay(200);
  digitalWrite(13,LOW);
  delay(100);
  digitalWrite(13,HIGH);
  delay(200);
  digitalWrite(13,LOW);
  digitalWrite(13,HIGH);
  delay(100);
  digitalWrite(13,LOW);
  delay(200);
  digitalWrite(13,HIGH);
  delay(100);
  digitalWrite(13,LOW);
}




void blinknok(){      // debug function "Blink no OK"
  delay(1000);
  digitalWrite(13,HIGH);
  delay(1000);
  digitalWrite(13,LOW);
  delay(300);
  digitalWrite(13,HIGH);
  delay(1000);
  digitalWrite(13,LOW);

}

void blinkbadnum(){    // debug function "Blink bad number"
   delay(1000);
  digitalWrite(13,HIGH);
  delay(2000);
  digitalWrite(13,LOW);
  delay(300);
  digitalWrite(13,HIGH);
  delay(1000);
  digitalWrite(13,LOW);
  delay(300);
  digitalWrite(13,HIGH);
  delay(1000);
  digitalWrite(13,LOW);
}

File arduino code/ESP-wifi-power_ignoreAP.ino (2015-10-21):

/* 
 *  
 *  This code is meant to be upload to a ESP8266 01 wifi module
 *  
 *  Refer to this guide to connect the ESP to Arduino UNO or MEGA:
 *  http://www.instructables.com/id/noobs-guide-to-ESP8266-with-Arduino-Mega-2560-or-U/
 *  
 *  The ESP8266WiFi library is required:
 *  https://github.com/esp8266/Arduino
 *  
 *  This code, upon receiving a "getdata" request from the serial port, scans the wifi networks nearby,
 *  and gives back via serial port, as absolut number, the power in dBm of the most powerful network.
 *  
 *  Created in October 2015 - Andrea Fasolo Rao for 2MONOCHANNELS
 *  raoandrea@gmail.com - giorgos@2monochannels.com
 *  
 */


#include <ESP8266WiFi.h> // ESP8266 Library

unsigned long waittime = 5000;      //wait time between networks scans
unsigned long lastscan = millis();

int bestNetworkID = 99;     //ID of the most powerful network 
int bestNetworkPower = 99;  //power in dBm of the most powerful network
int worstNetworkID = 99;    //ID of the less powerful network, unused
String bestNetworkSSID;     //SSID of the most powerful network

String inputString = "";         // a string to hold incoming data
boolean stringComplete = false;  // whether the string is complete

void setup() {               //this code runs once
  
  Serial.begin(115200);     //start serial communication. Speed depends on the revision of the module
  delay(10);
  
}

void loop() {               //this code keeps repeating

  serialEvent();            //check if data comming from serial port

    if (stringComplete) {                     //if the received String is complete...
      String bb=inputString.substring(0, 7);  //takes its first 7 characterss
      if (bb=="getdata"){                     //if the incoming String is "getdata"
         Serial.println(getdata());           //prints the result of the getdata() method, see line 56
         Serial.println();
      }
      inputString = "";                       //the String with the incoming characters is cleared
      stringComplete = false;                 //and the conditions set to false
    }

}

String getdata(){

    bestNetworkID = 99;
    worstNetworkID = 99;
    
    listNetworks();     //runs listNetwork() method, see line 78

    String message1 = String(bestNetworkPower);
    String message = String(message1+";");      //attaching a ";" character to the power of the best network
    return message;                             //this the value that will be sent via serial to the Arduino UNO
}

void serialEvent() {
      while (Serial.available()) {            //when the serial port is free...
          char inChar = (char)Serial.read();  //get the new byte from the serial port
          inputString += inChar;              //add it to the inputString
          if (inChar == '\n') {               //if the incoming character is a newline, set the string as complete
                stringComplete = true;
          }
      }
}

void listNetworks() {
  int numSsid = WiFi.scanNetworks();                  // scan for nearby networks:
  if (numSsid == -1) {                                //if there are no networks...
    Serial.println("Couldn't get a wifi connection"); //...prints an error
    bestNetworkPower = -99;                           //...and sets an invalid value
    while (true);                                     //wait to get networks SSIDs
    
  }

  //get the best connection:
  bestNetworkID = 0;
  for (int i = 1; i < numSsid; i++){      //this cycle finds the most powerful network, ignoring the one from the seat itself
    if ((WiFi.RSSI(i) > WiFi.RSSI(bestNetworkID)) && (String(WiFi.SSID(i)) != "Wifi-seat")){
      bestNetworkID = i;
    }
  }

  worstNetworkID = 0;
  for (int i = 1; i < numSsid; i++){    //this cycle finds the less powerful network
    if (WiFi.RSSI(i) < WiFi.RSSI(worstNetworkID)){
      worstNetworkID = i;
    }
  }

  bestNetworkPower = (WiFi.RSSI(bestNetworkID)*-1);   //dBm values are negative, this turns it to positive for convenience
  bestNetworkSSID = WiFi.SSID(bestNetworkID);

}

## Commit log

2015-10-01 will update dwg
    [wi-fi_seat.DWG]
2015-10-04 upload box dwg and photo
    [box.dwg]
2015-10-04 upload base dwgs
    [base.dwg]
2015-10-06 arduino board connections
2015-10-11 cost analysis, dwg modifications and pdf
    [base.dwg, box.dwg, cost_analysis.xlsx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]
2015-10-14 update cost analysis and plexiglass dwg
    [cost_analysis.xlsx, plexiglass.dwg]
2015-10-14 update plexiglass thickness
    [plan_elevation.dwg]
2015-10-14 update section and cost analysis
    [cost_analysis.xlsx, plan_elevation.dwg, plan_elevation_section.dwg]
2015-10-15 dxf and minor modifications
    [base.dxf, box.dxf, plan_elevation_section.dxf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]
2015-10-26 more images & updated cost
    [cost_analysis.xlsx]
2015-11-01 dwg numbering & minor modifications
    [A-01_plan_elevation_section.dwg, A-01_plan_elevation_section.dxf, A-02_base.dwg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]
2015-11-03 minor modifications
    [A-01_plan_elevation_section.dwg, A-01_plan_elevation_section.dxf, A-02_base.dwg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]
